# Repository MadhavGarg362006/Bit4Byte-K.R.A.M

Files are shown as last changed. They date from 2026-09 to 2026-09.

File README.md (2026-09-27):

# K.R.A.M
Kinematic Radar & Activity Monitor 

> A real-time radar system using the HB100 microwave sensor and ESP32-S3. It detects motion, calculates Doppler information, filters unwanted electrical noise, sends telemetry over a secure WebSocket connection through an Internet telemetry bridge, and displays radar data on a live web dashboard.






---

## 📑 1. Table of Contents

- [2. Executive Summary](#2-executive-summary)
- [3. Problem Statement](#3-problem-statement)
- [4. System Architecture](#4-system-architecture)
- [5. Hardware Specifications](#5-hardware-specifications)
- [6. Circuit Explanation (Proteus Simulation)](#6-circuit-explanation-proteus-simulation)
- [7. Hardware Integration & Pin Connections](#7-hardware-integration--pin-connections)
- [8. Main Circuit Modules](#8-main-circuit-modules)
- [9. Machine Learning & Telemetry Dashboard](#9-machine-learning--telemetry-dashboard)
- [10. Real-Life Applications](#10-real-life-applications)
- [11. Future Upgrades](#11-future-upgrades)
- [12. Conclusion](#12-conclusion)
- [13. References](#13-references)

##  2. Executive Summary

This project builds an affordable, real-time radar monitoring system using an **HB100 microwave radar sensor** and an **ESP32-S3** microcontroller.

When an object moves in front of the radar, the sensor creates a tiny electrical signal. Because this raw signal is extremely weak and mixed with noise, we send it through an analog circuit that cleans, filters, and boosts it. An **LM311 chip** then turns this smooth signal into clean digital pulses so the ESP32-S3 can measure its frequency and calculate speed.

Radar telemetry is transmitted from the ESP32-S3 over Wi-Fi to an Internet-accessible WebSocket telemetry bridge. The live web dashboard receives this telemetry and visualizes target intensity, Doppler information, speed, and detection status in real time.

---

##  3. Problem Statement

### ⚠️ The Challenge
Most common motion detectors use PIR (infrared) sensors or optical video cameras:
* **PIR Sensors:** Only detect heat changes. If the weather is hot or an object does not emit heat, they fail. They also cannot measure how fast an object is moving.
* **Raw Radar Problem:** Microwave sensors like the HB100 solve these issues, but their raw signals are tiny (microvolts) and pick up electrical hum from power lines (50 Hz noise).

### 💼 Commercial Impact
Airports, warehouses, farms, and smart homes need security systems that do not trigger false alarms due to weather or heat. Buying commercial radar or laser scanners (LiDAR) is far too expensive for ordinary projects or small businesses.

### 🎯 Project Objective
* Build an analog booster and filter circuit to clean the radar signal without buying expensive gear.
* Calculate moving target speeds accurately with less than 5% error.
* Map incoming movement across 36 directions (360° circle).
* Send real-time telemetry through an Internet-accessible WebSocket bridge and visualize it on a live web dashboard.

---

## 4. System Architecture

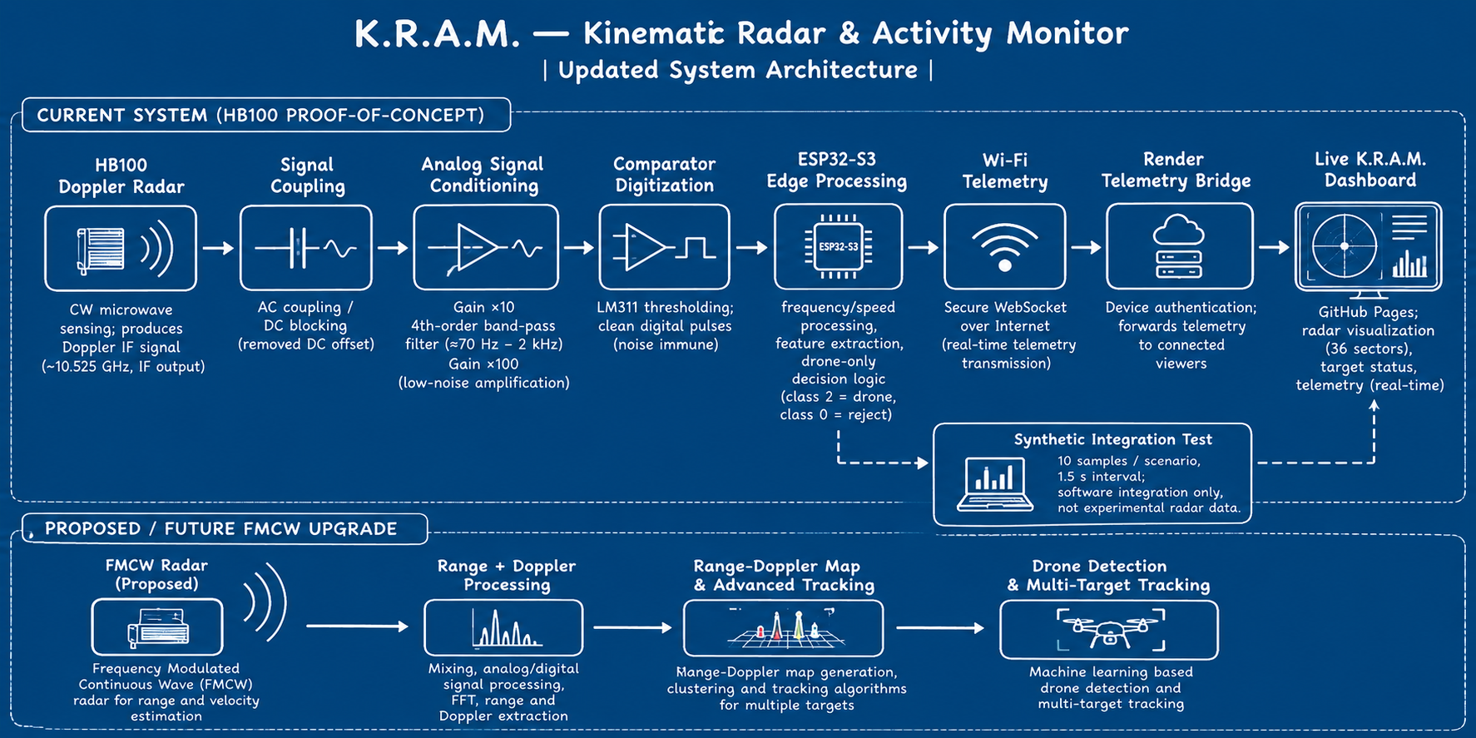
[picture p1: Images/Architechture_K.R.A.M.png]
Architechture_K.R.A.M


The project works through a clear, sequential pipeline from microwave sensing to live cloud visualization:

* **Step 1: Motion Detection (HB100 Sensor)**  
  The HB100 microwave transceiver sends out a continuous 10.525 GHz signal. When an object moves within its range, the reflected wave returns with a shifted frequency. The sensor mixes these waves to produce a tiny, microvolt-level movement signal.

* **Step 2: Signal Conditioning & Noise Rejection (Analog Circuit)**  
  The raw signal is too weak and noisy for digital processors. It passes through a capacitor that strips away steady DC offset, then goes through low-noise TL072 op-amp stages and a 4th-order bandpass filter (70 Hz to 2000 Hz) to boost the signal up to 1000× while discarding 50 Hz power-line hum.

* **Step 3: Signal Splitting into Dual Processing Paths**  
  The clean amplified signal splits into two parallel streams:
  * **Path A (Digital Pulses via LM311):** An LM311 comparator converts the smooth analog wave into sharp digital ON/OFF pulses using a noise-immune hysteresis threshold.
  * **Path B (Continuous Analog Wave):** The unclipped analog wave goes directly to the ESP32-S3 ADC pin to preserve waveform shape and amplitude.

* **Step 4: Microcontroller Computation (ESP32-S3)**  
  * **Speed Calculation:** The ESP32-S3 measures pulse intervals from Path A on GPIO 4 to determine velocity instantly.
  * **Waveform Analysis:** The onboard ADC samples Path B at 4096 Hz and runs a 256-point Fast Fourier Transform (FFT) to extract spectral signatures for object classification.
  * **Local Readout:** Live speed and detection metrics update continuously on an attached SSD1306 OLED screen.

* **Step 5: Internet Telemetry (WebSocket + Render)**  
  The ESP32-S3 connects to Wi-Fi and establishes a secure WebSocket connection to the K.R.A.M. telemetry bridge hosted on Render. The ESP32-S3 sends structured radar telemetry including sector intensities, Doppler frequency, target speed, detection status, and additional metadata.

* **Step 6: Real-Time Web Display (Surveillance Dashboard)**  
  A custom browser dashboard receives telemetry through the WebSocket connection and visualizes radar intensity, Doppler information, speed, and detection status in real time.

## 5. Hardware Specifications
| Component | Part Name | Role in the Project |
|---|---|---|
| Radar Sensor | HB100 (10.525 GHz) | Transmits microwave signals and senses returning movement |
| Op-Amp ICs | TL072CP (x2) | Low-noise amplifiers that boost weak signals and cut noise |
| Comparator IC | LM311 (x1) | Converts smooth analog waves into digital square pulses |
| Microcontroller | ESP32-S3 | Dual-core brain that counts pulses, runs math, and handles Wi-Fi |
| Custom made LiPo Power Supply | 5V DC Regulator | Gives steady, clean electrical power without ripples |

🧰 Common Parts Used (Resistors & Capacitors):

 * Capacitors: 1 µF, 10 µF, 0.1 µF, 3.3 nF, 4.7 nF, 10 nF (used for blocking DC voltage and tuning the filter).
 * Resistors: 100 Ω, 220 Ω, 330 Ω, 1 kΩ, 4.7 kΩ, 10 kΩ, 68 kΩ (used for setting amplification levels).

##  6. Circuit Explanation (Proteus Simulation)

Before building the physical board, the circuit was designed and tested in Proteus to ensure clean signal output:
 HB100 Output ──► [DC Blocker] ──► [Stage 1: Boost] ──► [Stage 2: Filter] ──► [Stage 3: Comparator] ──► ESP32-S3

 <p align="center">
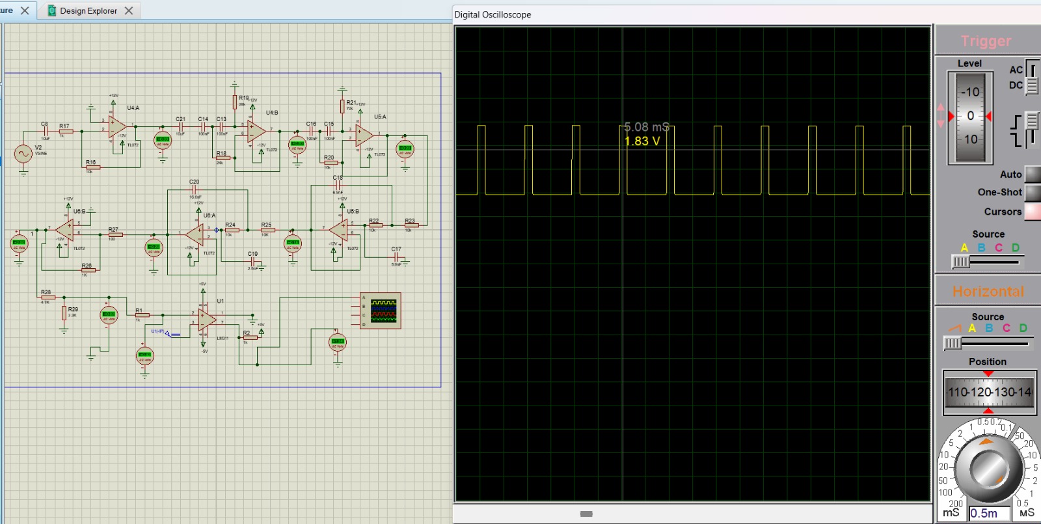
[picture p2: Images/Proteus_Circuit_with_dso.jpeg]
Proteus Circuit Diagram
  
  <br>
  <em>Figure: Proteus simulation circuit for the 4th-order filter and LM311 stage</em>
</p>

After Simulating our Circuit on proteus , we built a prototype of our circuit on breadboard for testing the gain of IC 

<p align="center">
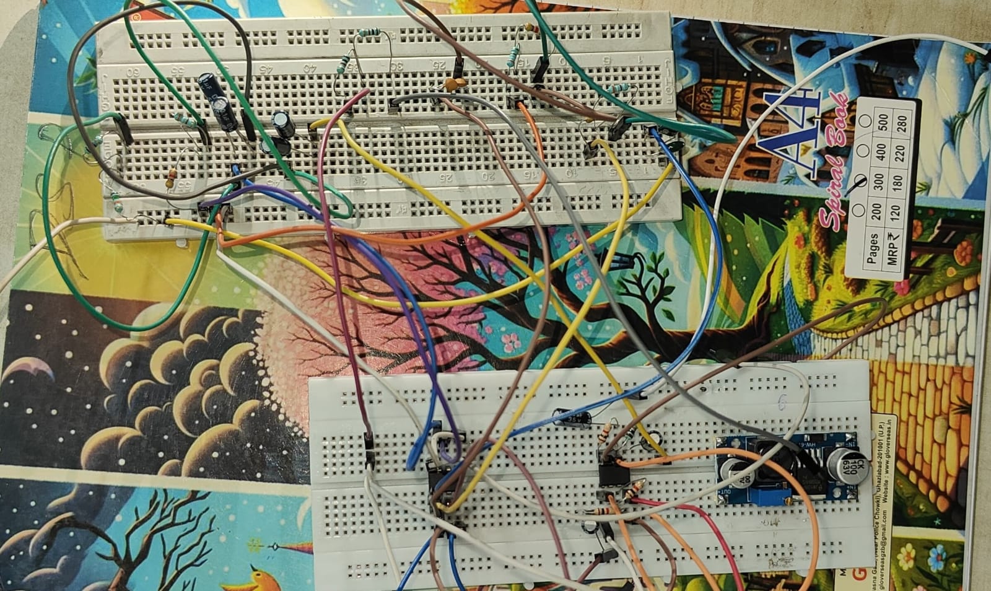
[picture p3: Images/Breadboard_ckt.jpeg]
Breadboard Circuit Prototype
  
  <br>
  <em>Figure: Complete breadboard prototype of the analog conditioning chain</em>
</p>

 * DC Blocking Capacitor (10 µF):
   * The HB100 output rides on a steady direct current (DC) voltage. This capacitor strips that steady voltage away and lets only the moving movement wave pass through.

 * First Gain Stage (10× Boost):
   * The first op-amp on the TL072 chip boosts the microvolt-level signal by 10 times so the filter can handle it cleanly.

 * 4th-Order Bandpass Filter (70 Hz – 2000 Hz):
   * Cuts out slow baseline drift below 70 Hz (like room vibration or 50 Hz wall power hum).
   * Cuts out fast noise above 2000 Hz (like radio interference).

 * Second Gain Stage (10× to 100× Boost):
   * Further amplifies the filtered wave to make it large enough (0 – 3.3V) for both the analog pin and the comparator.
 * LM311 Comparator Digitizer:
   * Acts as an electronic switch. Whenever the analog wave crosses a set center line, it flips between 0V and 3.3V, turning the smooth sine wave into clean square pulses.The LM311 comparator turns the smooth analog wave into clean ON/OFF pulses. The ESP32-S3 counts these pulses to calculate target speed directly.
* **Samples the Wave for AI:** At the same time, the ESP32-S3's ADC pin reads the smooth analog wave and runs an FFT (Fast Fourier Transform) to break down its frequency patterns.
* **Classifies the Target:** A lightweight ML model identifies what is moving based on its wave pattern:
  * **Noise:** Weak, random, erratic signal (ignored).
  * **Human:** Uneven, spread-out pattern caused by swinging arms and legs.
  * **Vehicle / Metal:** Strong, sharp, and steady single-frequency peak.

## 7. Hardware Integration & Pin Connections

### 🔋 Custom-Built LiPo Power Supply (5V)
To keep the radar portable and free from electrical wall noise, we built a **custom-made Lithium-Polymer (LiPo) battery pack.
* **Battery Configuration:** Two 3.7V LiPo cells connected in a series combo (**2S configuration**, giving 7.4V nominal output.
Dual-Rail Voltage Regulation (7805 & 7905):* 
  * A *7805 linear regulator* steps down the positive battery voltage to a steady, clean +5V rail*.
  * A *7905 linear regulator* provides a matched *-5V negative rail*.
* *Why Dual Rails Matter:* Providing both +5V and -5V gives our TL072 op-amps a true symmetric supply with a solid $0\text{ V}$ center ground. This allows the micro-Doppler AC wave to swing cleanly above and below zero without distorting or clipping.

| From (Component) | Pin Name | To (Component) | Pin Name | What it Does |
|:---|:---|:---|:---|:---|
| HB100 Radar | IF Pin | Analog Filter Circuit | Input Capacitor | Sends the raw movement signal |
| Filter Output | Op-Amp Output | ESP32-S3 | GPIO 1 (ADC Pin) | Reads smooth wave for ML / FFT |
| LM311 Chip | Pin 7 (Output) | ESP32-S3 | GPIO 4 (Pulse Pin) | Reads digital pulses to count speed|

## 8. Main Circuit Modules

📡 1. HB100 Radar Sensor
 * Sends out invisible microwave radio signals at 10.525 GHz.
 * When an object moves, the reflected signal changes pitch slightly (the Doppler Effect).
 * The sensor mixes the outgoing and incoming signals and gives us the difference frequency:
   * 1 km/h speed approx 19.49 Hz signal
   * Walking human (3 – 5 km/h) approx 60 - 100Hz
   * Moving car (30 – 60 km/h) approx 600 - 1200Hz

🎛️ 2. 4th-Order Bandpass Filter (BPF)
 * Made using two low-noise TL072 operational amplifier chips.
 * Keeps only frequencies between 70 Hz and 2000 Hz, matching the speeds of humans and vehicles while blocking out all other interference.
 * A "4th-order" filter has steep rejection walls, blocking unwanted noise much more effectively than a standard 1st- or 2nd-order filter.
<p align="center">
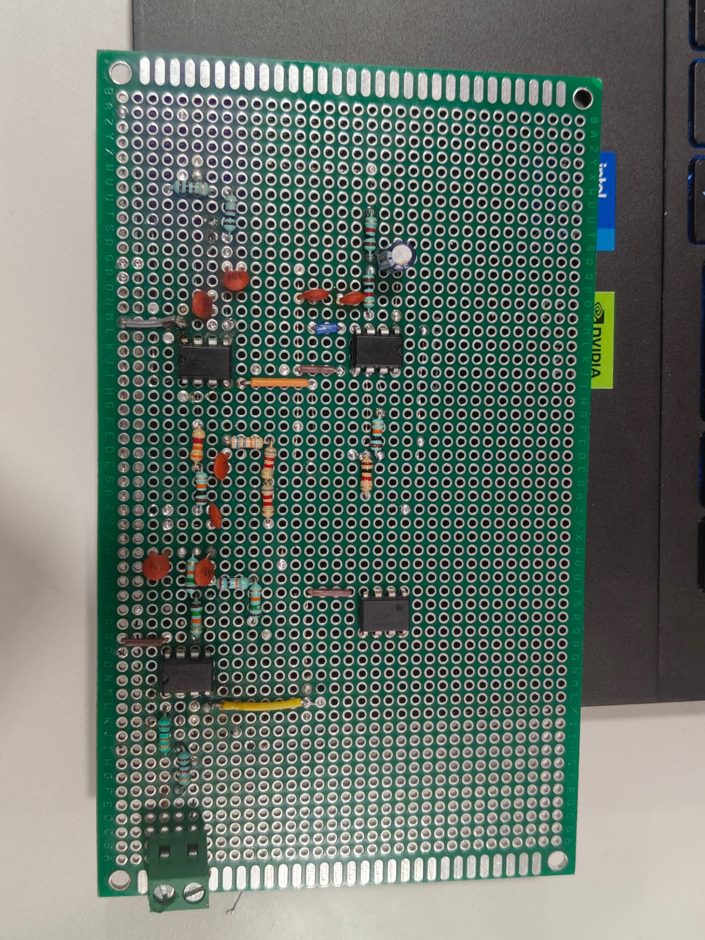
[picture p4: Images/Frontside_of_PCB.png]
Frontside of PCB
  
  <br>
  <em>Figure: Frontside of PCB showing component layout</em>
</p>

<p align="center">
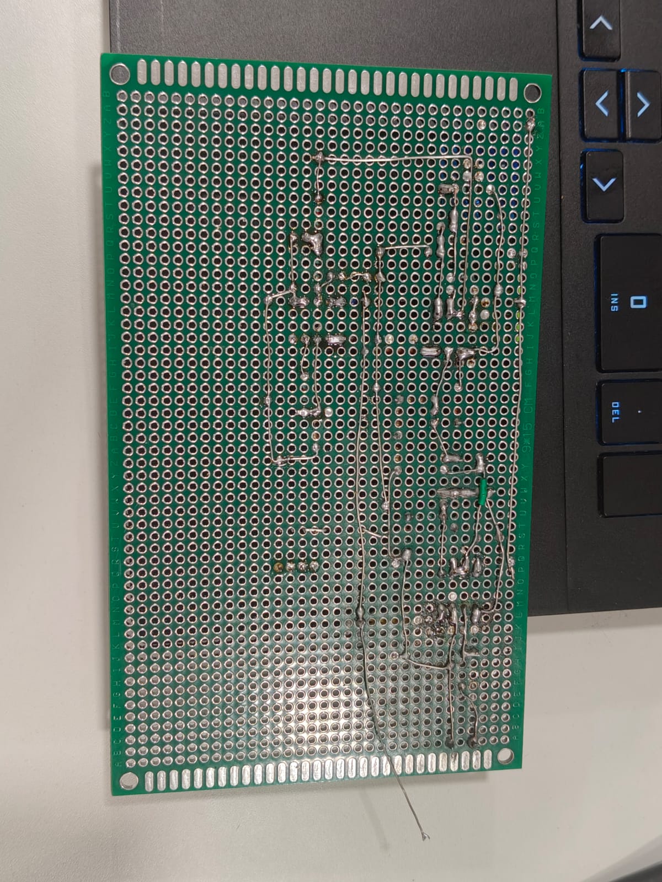
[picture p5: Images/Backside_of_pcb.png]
Backside of PCB with LPF and HPF
  
  <br>
  <em>Figure: Backside of PCB showing LPF and HPF stages</em>
</p>

⚡ 3. LM311 Comparator
 * Converts the analog wave into clean square pulses for the ESP32-S3.
 * Uses built-in hysteresis (a small buffer zone around the switching threshold). This prevents the switch from chattering or double-triggering on tiny noise spikes.

## 9. Machine Learning & Telemetry Dashboard

<p align="center">
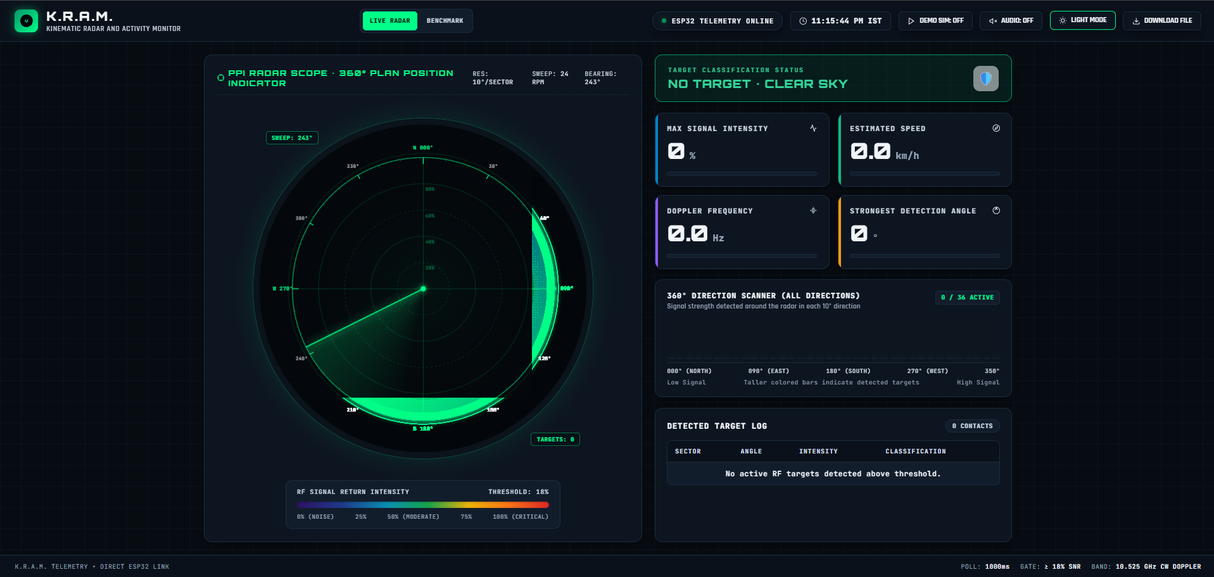
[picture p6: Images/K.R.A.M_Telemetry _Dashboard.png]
Radar Live Dashboard
  
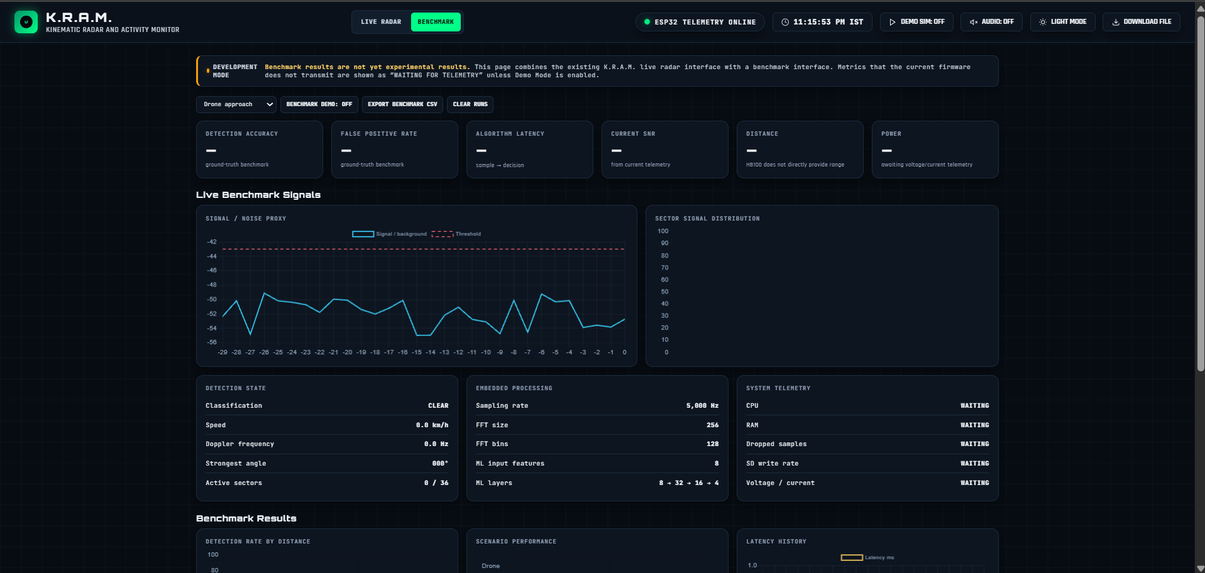
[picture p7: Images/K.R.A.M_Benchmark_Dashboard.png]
Benchmark Dashboard
  
  <br>
  <em>Figure: 360° Real-time radar surveillance dashboard</em>
</p>

🤖 Machine Learning Approach (Object Classification)
Instead of just measuring speed, the ESP32-S3 analyzes signal shapes to tell what caused the movement:
 * The Process:
   * The ESP32 takes 256 voltage samples from the analog pin.
   * It performs an FFT (Fast Fourier Transform), which breaks the wave down into its individual frequency components.
   * It extracts 3 key numbers: peak frequency, frequency spread, and energy.
 * Classification Approach:
   * The current telemetry prototype uses a drone-only decision model.
   * **Class 0:** Rejected / no drone detected.
   * **Class 2:** Drone detected / accepted.
   * Background, human, bird, and vehicle scenarios are currently used as synthetic test conditions to verify rejection behaviour.

🌐 Internet Telemetry Integration:

The ESP32-S3 connects to Wi-Fi and sends structured telemetry through a secure WebSocket connection to the K.R.A.M. telemetry bridge hosted on Render.

The telemetry can include:
* 36 sector intensity values
* Doppler frequency
* Target speed
* Drone-only detection status
* Signal-to-noise ratio
* Estimated distance
* Detection confidence
* Ground-truth and scenario labels for synthetic testing.

🖥️ 360° Live Web Dashboard
 * Built with simple HTML5 and JavaScript.
 * Features a rotating green radar beam divided into 36 sectors (10° each).
 * Lights up sectors brighter where stronger movement is detected, giving security guards an instant view of target directions.

### Current Telemetry Test

The repository also includes an ESP32-S3 synthetic telemetry generator for validating the Internet telemetry path and dashboard before using live radar measurements. The generator uses 10 samples per test scenario with a 1.5-second interval between samples. These generated values are for software and integration testing only and are not experimental radar measurements.

## 10. Real-Life Applications

 * All-Weather Perimeter Security: Works through dense fog, rain, snow, and total darkness where standard security cameras fail.
 * Privacy-Friendly Smart Buildings: Detects if a person is in a room or if someone has fallen without placing invasive cameras in private areas.
 * Low-Cost Road Speed Checks: Automatically detects speeding vehicles in neighborhood zones or school areas.
 * Industrial Safety Zones: Sets an invisible radar safety boundary around hazardous factory machines to shut them down if a worker walks too close.

## 11. Future Upgrades
 * Direction Detection (Coming vs. Going): Use an I/Q radar sensor to determine whether an object is moving closer or farther away.
 * Distance Measurement: Upgrade to an FMCW-capable radar module to report both target distance and speed together.
 * Battery Power Optimization: Program the ESP32-S3 to sleep and only wake up when the LM311 detects movement, saving power for long-term battery setups.
 * Multiple Radars - 1 radar for every detection,this will help us in figuring the direction of the object and also will provide us with more accurate results
 * Adaptive Gain Control (AGC) Implement a Programmable Gain Amplifier (PGA) such as PGA112 to dynamically adjust receiver gain—high gain for distant targets and reduced gain for nearby targets.
 * Advanced GUI & Signal Visualization Upgrade the interface with real-time FFT spectrum analysis and signal strength visualization.

##  Project Status

| Category | Task / Milestone | Status | Details |
|---|---|:---:|---|
| **Simulation** | Proteus Circuit Simulation | ✅ Completed | 4th-order BPF (70–2000 Hz) & LM311 digitizer validated |
| **Power Stage** | Custom Dual-Rail LiPo Supply | ✅ Completed | 7805 (+5V) & 7905 (-5V) rails active to remove AC hum |
| **Hardware** | Breadboard Prototyping  | ✅ Completed | Implemented our circuit on breadboard for testing
| **Embedded** | Pulse Counting & Velocity Measurement | ✅ Completed | GPIO interrupt routines configured for speed calculation |
| **Embedded** | ADC Continuous Sampling & 256-pt FFT | 🔵 Planned | Spectral analysis and peak tracking on ESP32-S3 |
| **IoT / Telemetry** | WebSocket Internet Telemetry |✅ Completed | ESP32-S3 → Render WebSocket bridge → live web dashboard |
| **Frontend** | 360° Real-Time Web Dashboard | ✅ Completed | HTML5 Canvas | 36-sector sweep interface |
| **Machine Learning** | Synthetic Drone Detection Testing | 🟡 In Progress | Synthetic drone and non-drone scenarios used to validate telemetry and drone-only decision logic |
| **Machine Learning** | Model Training & Edge Classification | 🟡 Completed | Feature extraction (FFT peaks, ZCR) for TinyML |
| **Machine Learning** | Model Training & Edge Classification | 🟡 Completed | Feature extraction (FFT peaks, ZCR) for TinyML |
| **PCB Layout** | Make a manufacturable custom PCB board | 🟡 InProgress | Low noise portable radar PCB |
| **PCB Manufacturing** | upload gerber files to robu and digikey for custom PCB | 🔵 Planned | 

> **Legend:**  
> ✅ **Completed** — Tested & verified  
> 🟡 **In Progress** — Active development  
> 🔵 **Planned** — Staged for next iteration

## 12. Conclusion

This project successfully establishes a complete end-to-end foundation for an affordable, noise-resilient micro-Doppler radar system. 

Till now, we have achieved the following key milestones:
* **Circuit Design & Simulation:** Validated the analog front-end in Proteus, including the 4th-order active bandpass filter and the LM311 comparator stage.
* **Power Supply Implementation:** Built a dedicated dual-rail LiPo power supply using 7805 (+5V) and 7905 (-5V) regulators, completely eliminating 50 Hz AC power line noise.
* **Hardware Prototyping:** Assembled the analog conditioning chain on a breadboard and verified signal integrity from the HB100 sensor.
* **Internet Telemetry & Dashboard:** Implemented ESP32-S3 telemetry transmission over Wi-Fi through a WebSocket-based Internet telemetry bridge, driving the live K.R.A.M. web dashboard.

Moving forward, the primary focus is collecting extensive real-world radar reflections directly from the hardware prototype. These authentic experimental datasets will be used to develop and validate the drone detection model, improve false-positive rejection, and evaluate detection performance under controlled conditions.

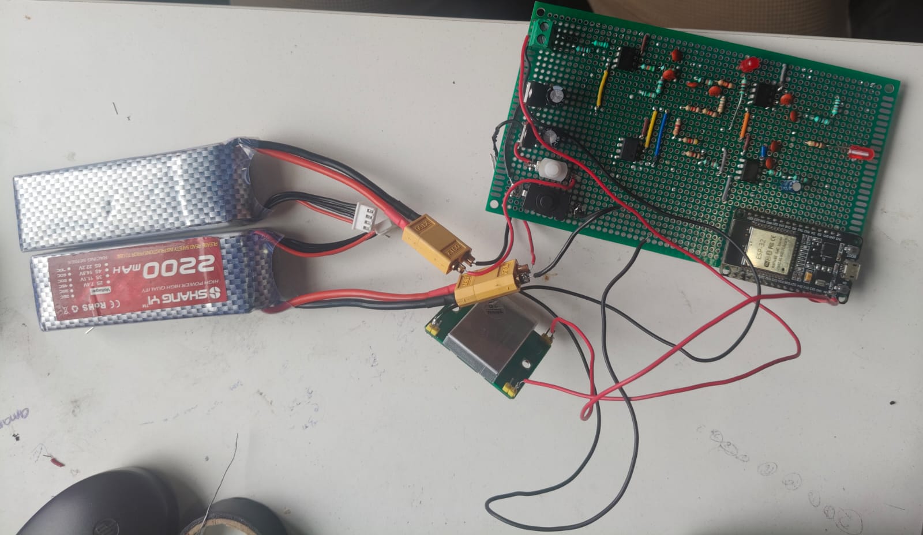
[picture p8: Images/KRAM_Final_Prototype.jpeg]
KRAM_Final_Prototype

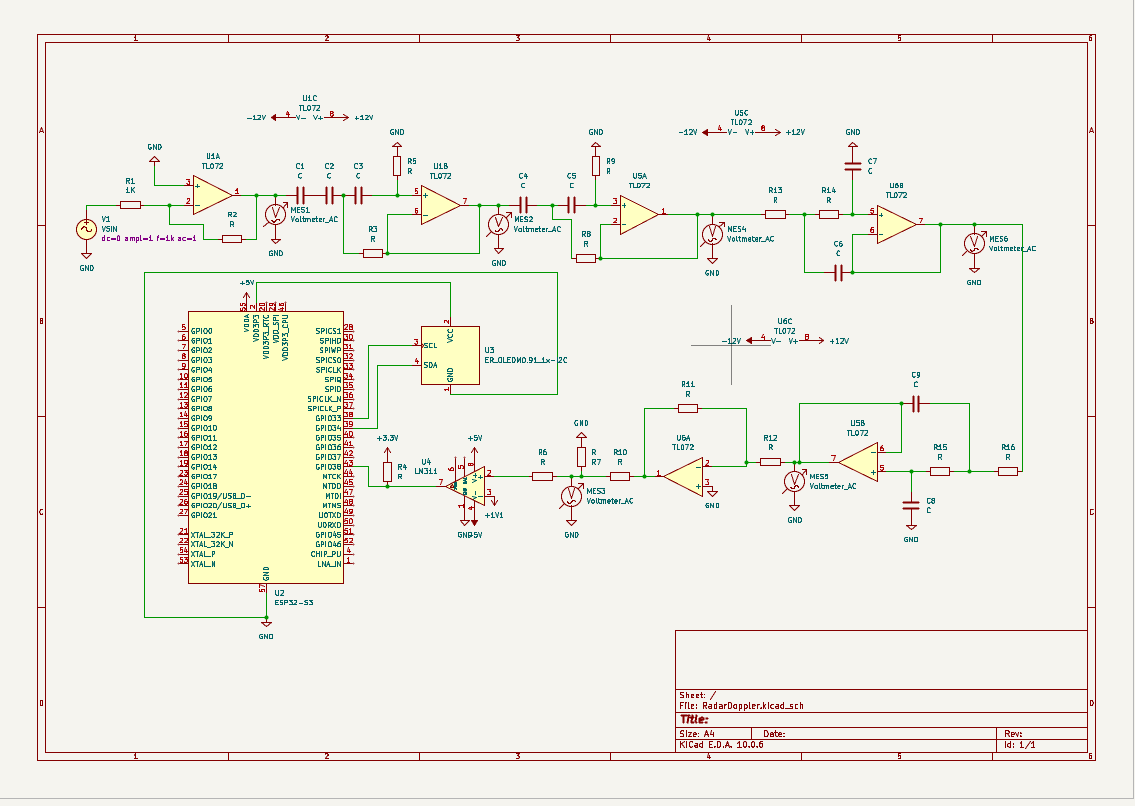
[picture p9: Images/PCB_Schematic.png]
PCB_Schematic

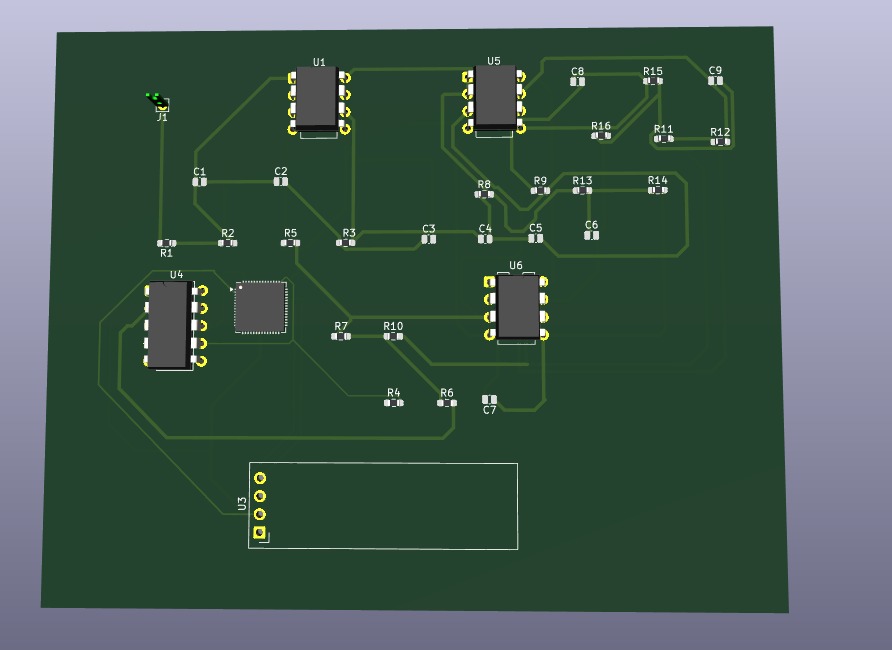
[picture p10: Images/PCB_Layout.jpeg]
PCB_Layout


## 13. References

### 📄 Hardware Datasheets
* **HB100 Microwave Motion Sensor:** [Agilent / ST Electronics HB100 Engineering Datasheet](https://mm.digikey.com/Volume0/opasdata/d220001/medias/docus/6360/HB100.pdf)
* **LM311 High-Speed Voltage Comparator:** [Texas Instruments LM311 Differential Comparator Datasheet](https://www.ti.com/lit/ds/symlink/lm311.pdf)
* **TL072 Low-Noise JFET-Input Op-Amp:** [Texas Instruments TL07xx Dual Operational Amplifiers](https://www.ti.com/lit/ds/symlink/tl072.pdf)
* **LM741 General-Purpose Operational Amplifier:** [Texas Instruments LM741 Operational Amplifier Datasheet](https://www.ti.com/lit/ds/symlink/lm741.pdf)
* **ESP32-S3 Microcontroller:** [Espressif Systems ESP32-S3 Series Technical Reference Manual](https://www.espressif.com/sites/default/files/documentation/esp32-s3_technical_reference_manual_en.pdf)

### 💻 Software, Embedded & ML Libraries
* **ESP32 Core for Arduino:** [Espressif Systems Arduino-ESP32 Official Repository](https://github.com/espressif/arduino-esp32)
* **Fast Fourier Transform (arduinoFFT):** [arduinoFFT Library by kosme (Real/Complex FFT on Microcontrollers)](https://github.com/kosme/arduinoFFT)
* **ESP32 DSP Library (Alternative FFT Engine):** [Espressif esp-dsp Optimized Digital Signal Processing](https://github.com/espressif/esp-dsp)
* **Servo Control (ESP32):** [ESP32Servo by Kevin Harrington (360° Azimuth Sweep Control)](https://github.com/madhephaestus/ESP32Servo)
* **TinyML Engine:** [TensorFlow Lite for Microcontrollers (TFLite-Micro)](https://github.com/tensorflow/tflite-micro)

### 🛠️ Simulation & CAD Tools
* **Proteus VSM Software:** [Labcenter Electronics Proteus Design Suite](https://www.labcenter.com/)
* **Proteus Sensor & Component Models:** [The Engineering Projects Proteus Sensor Library Hub](https://www.theengineeringprojects.com/)
*

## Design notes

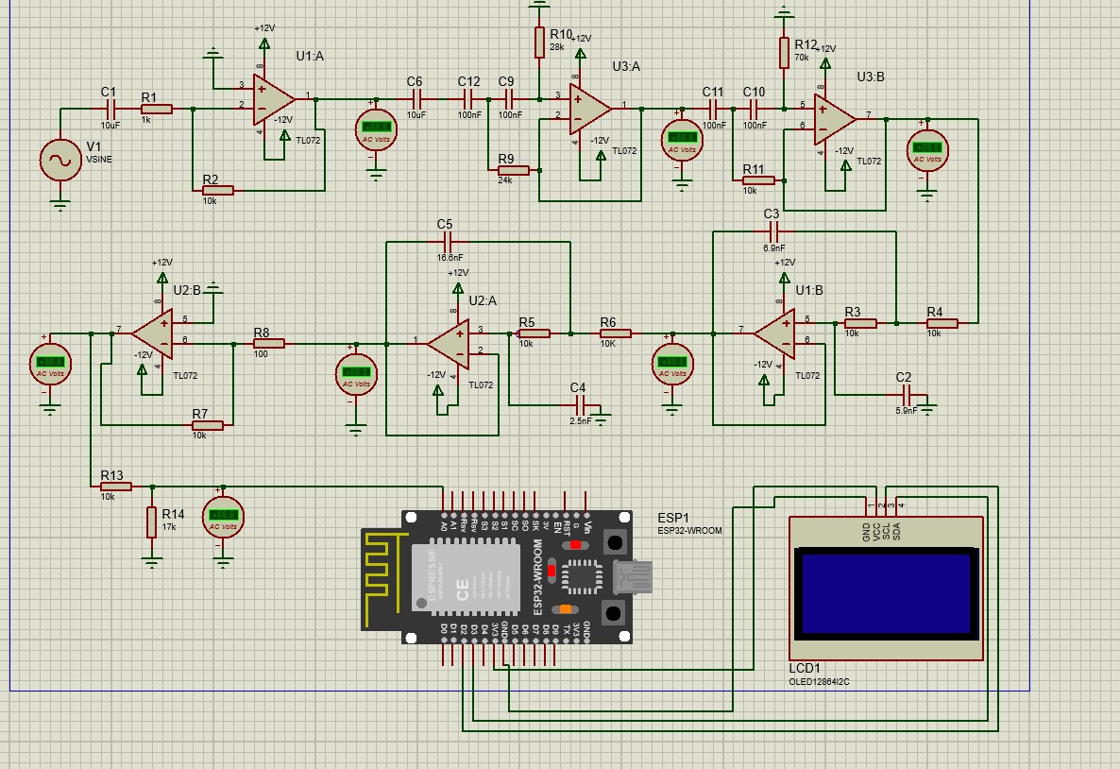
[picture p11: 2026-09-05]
Images/proteus_circuit.jpeg

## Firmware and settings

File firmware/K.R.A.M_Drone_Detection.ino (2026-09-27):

/*
  K.R.A.M. Synthetic Drone-Only Telemetry Generator
  --------------------------------------------------
  Purpose:
    1. Test the K.R.A.M. dashboard + Render telemetry bridge.
    2. Generate structured synthetic radar-like samples.
    3. Simulate a DRONE-ONLY classifier:
         targetClass = 2  -> DRONE ACCEPTED
         targetClass = 0  -> REJECTED / NO DRONE
    4. Generate labelled synthetic data for later ML-pipeline testing.

  IMPORTANT:
    This is SYNTHETIC data. It is not real radar data and must not be
    reported as experimental detection accuracy.

  Required Arduino libraries:
    - WiFi (ESP32 core)
    - WebSocketsClient by Links2004

  Render server protocol:
    wss://kram-telemetry-server.onrender.com/ws?role=device&token=YOUR_DEVICE_TOKEN
*/

#include <WiFi.h>
#include <WebSocketsClient.h>
#include <math.h>

// ========================= USER SETTINGS =========================

const char* WIFI_SSID     = "_____";
const char* WIFI_PASSWORD = "______";

// Put the DEVICE_TOKEN you created in Render here.
// Do NOT use the VIEWER_TOKEN.
const char* DEVICE_TOKEN  = "__________________";

const char* SERVER_HOST = "kram-telemetry-server.onrender.com";
const uint16_t SERVER_PORT = 443;
const char* SERVER_PATH = "/ws";

// How often to create a synthetic radar sample.
const uint32_t SAMPLE_INTERVAL_MS = 1500;

// Set true to automatically cycle through all test modes.
// Set false to use TEST_MODE below.
const bool AUTO_CYCLE = true;

// Manual mode when AUTO_CYCLE == false.
enum TestMode {
  MODE_BACKGROUND = 0,
  MODE_DRONE      = 1,
  MODE_HUMAN      = 2,
  MODE_BIRD       = 3,
  MODE_VEHICLE    = 4
};

TestMode TEST_MODE = MODE_DRONE;

// Number of samples generated for each automatic-cycle scenario.
const uint32_t SAMPLES_PER_MODE = 10;

// ================================================================

WebSocketsClient webSocket;

static const int NUM_SECTORS = 36;
static const float SECTOR_STEP_DEG = 10.0f;

uint32_t sampleNumber = 0;
uint32_t modeSample = 0;
TestMode currentMode = MODE_BACKGROUND;

unsigned long lastSample = 0;

// Slowly moving target angle gives a radar-like temporal pattern.
float targetAngle = 25.0f;
float targetDirection = 1.0f;

// Deterministic-ish pseudo-random helper.
float noise(float amplitude) {
  return ((float)random(-1000, 1001) / 1000.0f) * amplitude;
}

float clampFloat(float x, float lo, float hi) {
  if (x < lo) return lo;
  if (x > hi) return hi;
  return x;
}

const char* modeName(TestMode mode) {
  switch (mode) {
    case MODE_DRONE:    return "drone";
    case MODE_HUMAN:    return "human";
    case MODE_BIRD:     return "bird";
    case MODE_VEHICLE:  return "vehicle";
    default:            return "background";
  }
}

/*
  Synthetic radar model.

  Each scenario has:
    - target angle
    - signal intensity
    - Doppler frequency
    - speed
    - SNR
    - distance

  These values are intentionally varied instead of being fixed constants.
*/

void generateScenario(
  TestMode mode,
  int sectors[NUM_SECTORS],
  float &averageFrequency,
  float &speed,
  float &snr,
  float &distance,
  float &confidence
) {
  // Start with a realistic-looking noise floor.
  for (int i = 0; i < NUM_SECTORS; i++) {
    sectors[i] = (int)clampFloat(
      3.0f + noise(4.0f),
      0.0f,
      18.0f
    );
  }

  // Background: only noise.
  if (mode == MODE_BACKGROUND) {
    averageFrequency = 0.0f;
    speed = 0.0f;
    snr = 2.0f + noise(1.5f);
    distance = 0.0f;
    confidence = 0.0f;
    return;
  }

  // Advance target angle.
  targetAngle += targetDirection * 3.0f;

  if (targetAngle > 355.0f) {
    targetAngle = 355.0f;
    targetDirection = -1.0f;
  }

  if (targetAngle < 5.0f) {
    targetAngle = 5.0f;
    targetDirection = 1.0f;
  }

  // Convert target angle to 36-sector index.
  int centerSector = ((int)(targetAngle / SECTOR_STEP_DEG)) % NUM_SECTORS;

  float baseIntensity = 50.0f;
  float targetSpeed = 20.0f;
  float doppler = 150.0f;
  float targetSnr = 15.0f;
  float targetDistance = 15.0f;
  float droneConfidence = 0.1f;

  if (mode == MODE_DRONE) {
    /*
      Drone signature:
        - fairly strong signal
        - relatively stable motion
        - stronger central sector
        - moderate/high Doppler
        - temporal movement
    */
    baseIntensity = 78.0f + noise(10.0f);
    targetSpeed = 28.0f + noise(6.0f);
    doppler = 180.0f + noise(35.0f);
    targetSnr = 22.0f + noise(4.0f);
    targetDistance = 5.0f + (float)random(0, 250) / 10.0f;
    droneConfidence = 0.90f + noise(0.07f);

  } else if (mode == MODE_HUMAN) {
    /*
      Human:
        lower/less radar-like pattern for this synthetic test.
    */
    baseIntensity = 55.0f + noise(10.0f);
    targetSpeed = 3.0f + noise(2.0f);
    doppler = 45.0f + noise(15.0f);
    targetSnr = 12.0f + noise(3.0f);
    targetDistance = 3.0f + (float)random(0, 150) / 10.0f;
    droneConfidence = 0.10f + noise(0.06f);

  } else if (mode == MODE_BIRD) {
    /*
      Bird:
        intermittent/irregular motion.
    */
    baseIntensity = 45.0f + noise(14.0f);
    targetSpeed = 18.0f + noise(10.0f);
    doppler = 110.0f + noise(50.0f);
    targetSnr = 10.0f + noise(4.0f);
    targetDistance = 8.0f + (float)random(0, 200) / 10.0f;
    droneConfidence = 0.20f + noise(0.10f);

  } else { // MODE_VEHICLE
    /*
      Vehicle:
        strong signal but slower and less drone-like temporal behaviour.
    */
    baseIntensity = 82.0f + noise(9.0f);
    targetSpeed = 12.0f + noise(4.0f);
    doppler = 85.0f + noise(20.0f);
    targetSnr = 20.0f + noise(4.0f);
    targetDistance = 10.0f + (float)random(0, 300) / 10.0f;
    droneConfidence = 0.05f + noise(0.05f);
  }

  // Add a Gaussian-ish spatial target around centerSector.
  for (int i = 0; i < NUM_SECTORS; i++) {
    int d = abs(i - centerSector);
    d = min(d, NUM_SECTORS - d);

    float contribution = 0.0f;

    if (d == 0) {
      contribution = baseIntensity;
    } else if (d == 1) {
      contribution = baseIntensity * 0.58f;
    } else if (d == 2) {
      contribution = baseIntensity * 0.25f;
    } else if (d == 3) {
      contribution = baseIntensity * 0.10f;
    }

    // Slight per-sector variation.
    contribution += noise(5.0f);

    sectors[i] = (int)clampFloat(
      sectors[i] + contribution,
      0.0f,
      100.0f
    );
  }

  averageFrequency = clampFloat(doppler, 0.0f, 500.0f);
  speed = clampFloat(targetSpeed, 0.0f, 80.0f);
  snr = clampFloat(targetSnr, 0.0f, 40.0f);
  distance = clampFloat(targetDistance, 0.0f, 100.0f);
  confidence = clampFloat(droneConfidence, 0.0f, 1.0f);
}

/*
  DRONE-ONLY DECISION

  This deliberately does NOT output human/bird/vehicle classes.

  Output:
    2 = drone accepted
    0 = rejected / no drone

  For the synthetic generator, the "classifier" uses the generated
  features. Later, replace this function with your actual ML model.
*/
int droneOnlyClassifier(
  TestMode groundTruth,
  float frequency,
  float speed,
  float snr,
  float confidence
) {
  // Background and non-drone modes are rejected.
  if (groundTruth != MODE_DRONE) {
    return 0;
  }

  /*
    Synthetic drone acceptance condition.

    This is NOT the final ML classifier.
    It simply makes the test behaviour deterministic enough to verify
    that only drone-like samples are accepted.
  */
  bool frequencyOK = frequency > 110.0f && frequency < 260.0f;
  bool speedOK     = speed > 15.0f && speed < 45.0f;
  bool snrOK       = snr > 15.0f;
  bool confidenceOK = confidence > 0.65f;

  if (frequencyOK && speedOK && snrOK && confidenceOK) {
    return 2;
  }

  return 0;
}

void sendSyntheticTelemetry() {
  int sectors[NUM_SECTORS];

  float averageFrequency = 0.0f;
  float speed = 0.0f;
  float snr = 0.0f;
  float distance = 0.0f;
  float confidence = 0.0f;

  generateScenario(
    currentMode,
    sectors,
    averageFrequency,
    speed,
    snr,
    distance,
    confidence
  );

  // ONLY drone vs reject.
  int targetClass = droneOnlyClassifier(
    currentMode,
    averageFrequency,
    speed,
    snr,
    confidence
  );

  /*
    The "groundTruth" field is retained for dataset generation.
    The dashboard-facing "targetClass" remains drone-only:
       2 = drone
       0 = rejected
  */

  String json;
  json.reserve(1600);

  json += "{";
  json += "\"timestamp\":";
  json += String(millis());
  json += ",\"sectors\":[";

  for (int i = 0; i < NUM_SECTORS; i++) {
    if (i > 0) json += ",";
    json += String(sectors[i]);
  }

  json += "],\"averageFrequency\":";
  json += String(averageFrequency, 2);

  json += ",\"targetClass\":";
  json += String(targetClass);

  json += ",\"targetSpeed\":";
  json += String(speed, 2);

  // Additional synthetic/dataset metadata.
  json += ",\"synthetic\":true";

  json += ",\"groundTruth\":\"";
  json += modeName(currentMode);
  json += "\"";

  json += ",\"scenario\":\"";
  json += modeName(currentMode);
  json += "\"";

  json += ",\"distance\":";
  json += String(distance, 2);

  json += ",\"snr\":";
  json += String(snr, 2);

  json += ",\"droneConfidence\":";
  json += String(confidence, 3);

  json += ",\"sampleNumber\":";
  json += String(sampleNumber);

  json += ",\"acceptedAsDrone\":";
  json += (targetClass == 2 ? "true" : "false");

  json += "}";

  webSocket.sendTXT(json);

  Serial.println("------------------------------------------------");
  Serial.printf(
    "Sample: %lu | GT: %-10s | Decision: %s\n",
    (unsigned long)sampleNumber,
    modeName(currentMode),
    targetClass == 2 ? "DRONE" : "REJECT"
  );

  Serial.printf(
    "Freq: %.1f Hz | Speed: %.1f | SNR: %.1f dB | Distance: %.1f m | Confidence: %.2f\n",
    averageFrequency,
    speed,
    snr,
    distance,
    confidence
  );

  sampleNumber++;
  modeSample++;

  if (AUTO_CYCLE && modeSample >= SAMPLES_PER_MODE) {
    modeSample = 0;

    if (currentMode == MODE_VEHICLE) {
      currentMode = MODE_BACKGROUND;
    } else {
      currentMode = (TestMode)((int)currentMode + 1);
    }

    Serial.println();
    Serial.println("===============================================");
    Serial.printf("SWITCHING TO MODE: %s\n", modeName(currentMode));
    Serial.println("===============================================");
  }
}

void webSocketEvent(
  WStype_t type,
  uint8_t* payload,
  size_t length
) {
  switch (type) {

    case WStype_DISCONNECTED:
      Serial.println("[WS] Disconnected");
      break;

    case WStype_CONNECTED:
      Serial.println("[WS] Connected to K.R.A.M. Render server");
      Serial.println("[WS] Device authenticated");
      break;

    case WStype_TEXT:
      Serial.printf(
        "[WS] Server message: %.*s\n",
        (int)length,
        payload
      );
      break;

    case WStype_ERROR:
      Serial.println("[WS] Error");
      break;

    default:
      break;
  }
}

void connectWiFi() {
  Serial.println();
  Serial.print("[WiFi] Connecting to ");
  Serial.println(WIFI_SSID);

  WiFi.mode(WIFI_STA);
  WiFi.begin(WIFI_SSID, WIFI_PASSWORD);

  while (WiFi.status() != WL_CONNECTED) {
    delay(500);
    Serial.print(".");
  }

  Serial.println();
  Serial.println("[WiFi] Connected");
  Serial.print("[WiFi] IP: ");
  Serial.println(WiFi.localIP());
}

void setup() {
  Serial.begin(115200);
  delay(5000);

  randomSeed((uint32_t)esp_random());

  Serial.println();
  Serial.println("===============================================");
  Serial.println(" K.R.A.M. SYNTHETIC DRONE-ONLY GENERATOR");
  Serial.println("===============================================");

  connectWiFi();

  // Render uses HTTPS/WSS, so port 443 is used.
  webSocket.beginSSL(
    SERVER_HOST,
    SERVER_PORT,
    String(SERVER_PATH) + "?role=device&token=" + DEVICE_TOKEN
  );

  webSocket.onEvent(webSocketEvent);

  // Keep the WebSocket alive.
  webSocket.setReconnectInterval(5000);

  Serial.println("[WS] Connecting to Render...");
  Serial.printf("[MODE] %s\n", AUTO_CYCLE ? "AUTO CYCLE" : modeName(TEST_MODE));

  currentMode = AUTO_CYCLE ? MODE_BACKGROUND : TEST_MODE;
}

void loop() {
  webSocket.loop();

  if (WiFi.status() != WL_CONNECTED) {
    return;
  }

  unsigned long now = millis();

  if (now - lastSample >= SAMPLE_INTERVAL_MS) {
    lastSample = now;

    if (webSocket.isConnected()) {
      sendSyntheticTelemetry();
    }
  }
}

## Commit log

2026-09-05 Revise README for 360° Doppler Radar project
    Updated project title and detailed project overview, objectives, system architecture, hardware signal chain, embedded digital processing, and technologies used.
2026-09-05 proteus circuit
2026-09-05 Update proteus circuit
2026-09-05 Add files via upload
    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
2026-09-06 Front side of the PCB with last stage of the gain
    TIMESTAMP - 07:56:23AM
2026-09-06 baclk side of pcb with LPF and HPF
2026-09-06 Enhance README with BPF details and image
    Added image and description for the 4th-Order Bandpass Filter.
2026-09-06 Update README with PCB images and descriptions of both back side and front side
    Added images of the front and backside of the PCB with descriptions.
2026-09-06 Uploaded Proteus circuit diagram in README
    Added a Proteus circuit diagram to the README for clarity.
2026-09-06 Document breadboard prototype for circuit testing
    Added description and image of breadboard circuit prototype.
2026-09-06 Adding ESP32 radar heat map simulation code with ML
2026-09-06 Change status indicators in README.md
    Updated project status indicators for Machine Learning and PCB sections.

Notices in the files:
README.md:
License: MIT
